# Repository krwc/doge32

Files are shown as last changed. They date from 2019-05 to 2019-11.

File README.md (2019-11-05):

# DOGE32 Features

## Small footprint

The board is 25mm x 59mm, which means it can fit into the standard breadboard nicely, and
each pin will be accessible.

## Battery slot

The board can be powered by 3.7V li-po battery.

## Low power consumption

In deep sleep mode, the board consumes only about 13µA. This is a pretty good result and will
let the device work for a long period of time on a battery.

## Dual supply support

You may power the device from battery as well as from the USB at the same time - useful feature
if you're making some quick fixes to the "already deployed" device.

## Built-in voltage measurement on IO35 pin

The IO35 pin of the ESP32 is connected to the (switchable via IO32), to avoid excessive current
draw input voltage divider, and can be used to determine the battery level of the battery.

## Cutting off the USB-UART converter when powered on from the battery

Many ESP32 boards don't do it, which is a problem, because [not all revisions of CP2102N enter
suspend state correctly](https://www.silabs.com/documents/public/errata/cp2102n-errata.pdf),
which means they draw current (a few milliamps) when they are not supposed to (e.g. when powered
on from the battery). This issue is fixed in our board.

## Slow rising reset fix

[ESP32 has a bug](https://www.esp32.com/viewtopic.php?t=5731) that makes automatic reset during
flashing with tools such as esptool.py not happening, and thus requires manual user intervention.

Our board also incorporates the fix for this problem.

# Renders

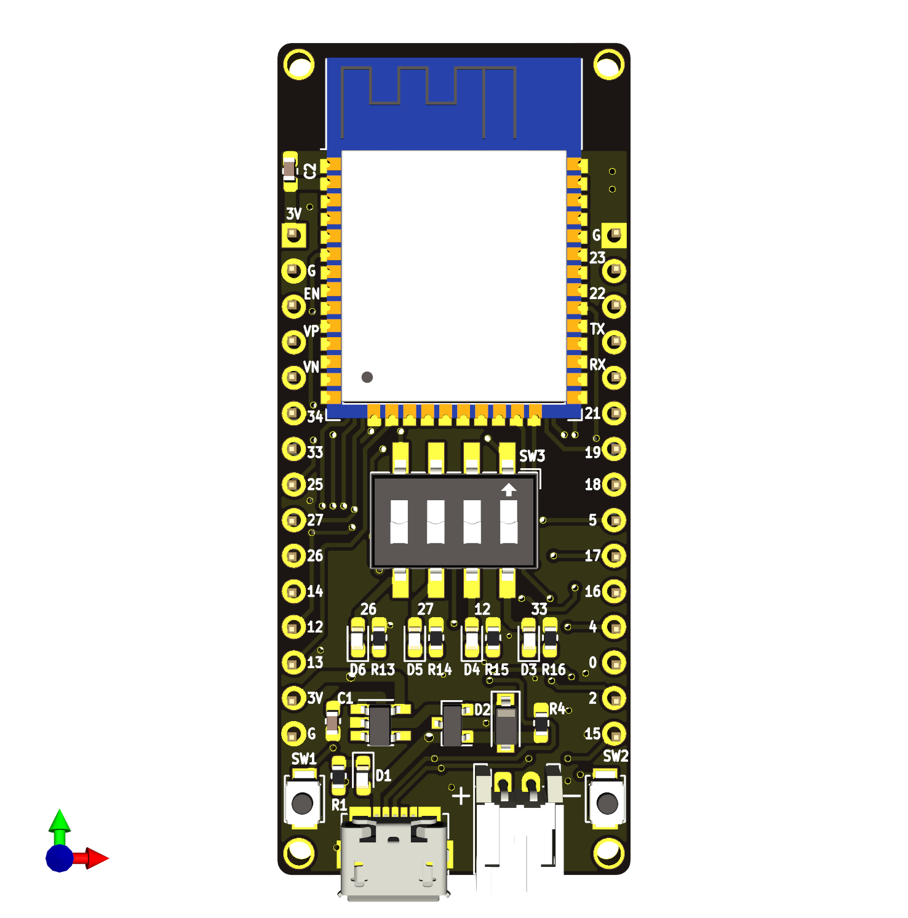
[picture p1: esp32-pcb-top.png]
Top


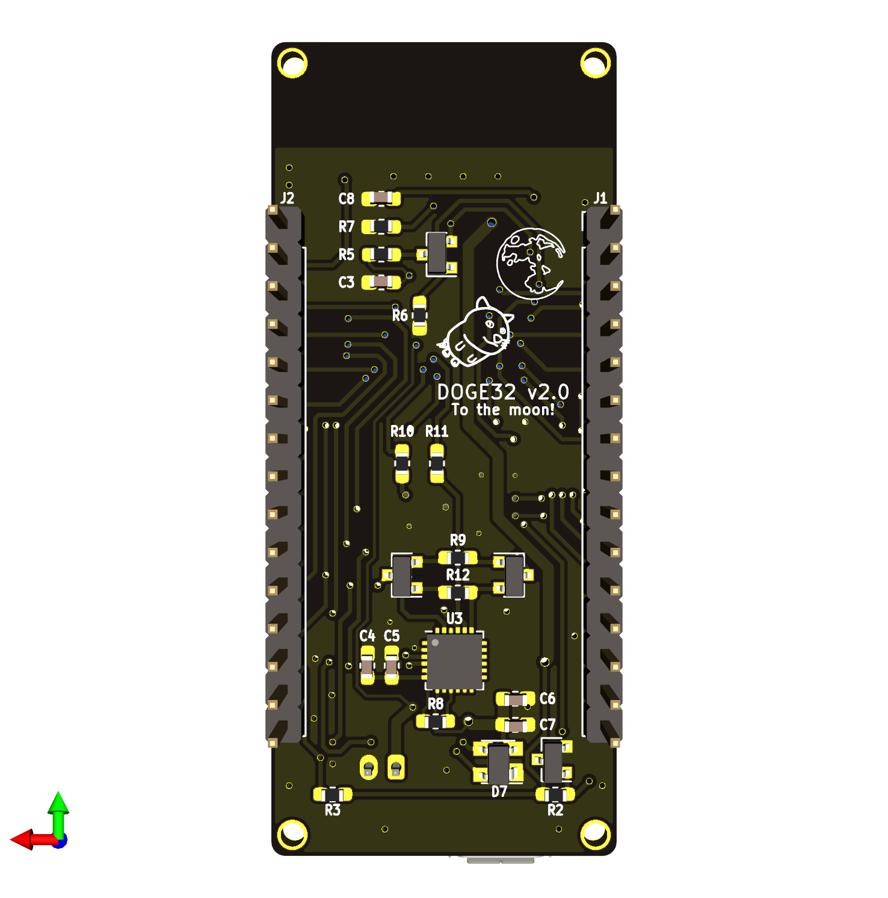
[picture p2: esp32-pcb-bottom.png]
Bottom


# Authors

Me and [dextero](https://github.com/dextero/). The board is an absolute overkill, built to monitor
soil moisture and eventually to help reminiding about watering plants more often ;-).

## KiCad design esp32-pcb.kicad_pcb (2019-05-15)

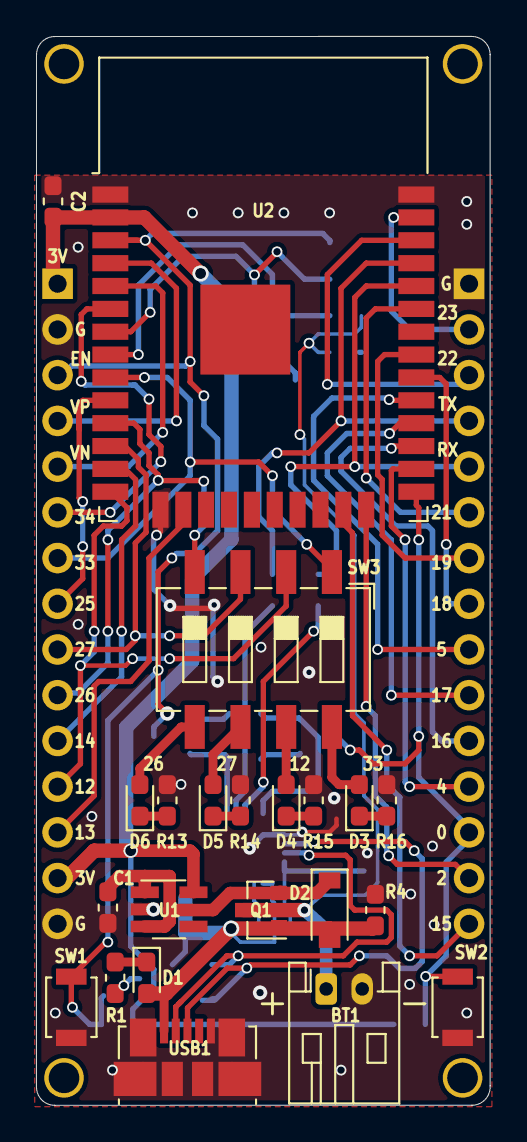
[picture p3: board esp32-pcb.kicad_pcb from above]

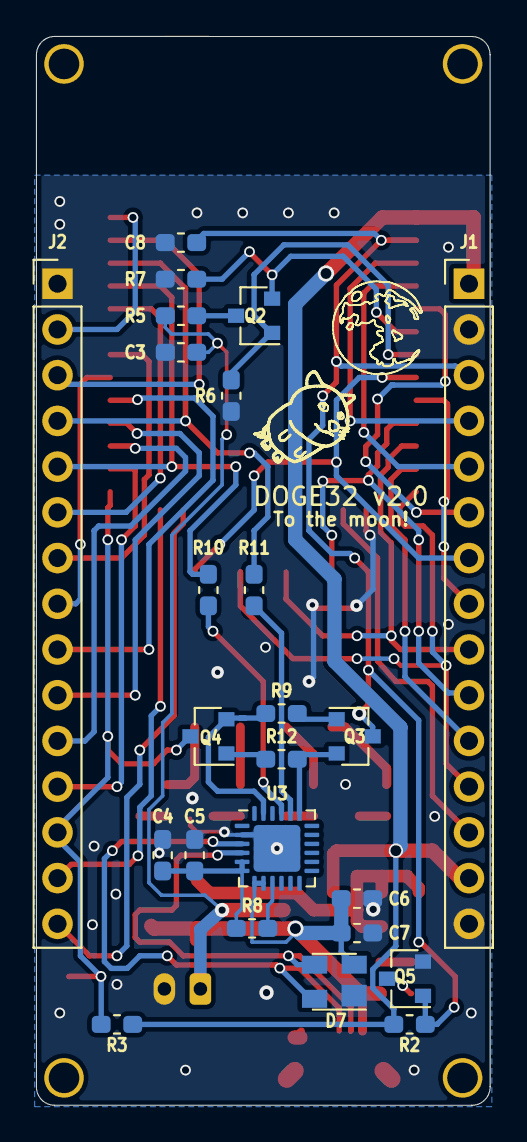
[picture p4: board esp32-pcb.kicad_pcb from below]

Board: 2 copper layers, 25.2 x 59.4 mm, 46 parts (24 on the bottom side), 53 nets.

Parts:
BT1: 3.7V; JST_PH_S2B-PH-K_1x02_P2.00mm_Horizontal
C1, C2: 10uF; C_0603_1608Metric_Pad1.05x0.95mm_HandSolder
C3, C5, C7: 0.1uF; C_0603_1608Metric_Pad1.05x0.95mm_HandSolder
C4, C6, C8: 4.7uF; C_0603_1608Metric_Pad1.05x0.95mm_HandSolder
D1: LED_USB_PWR; LED_0603_1608Metric_Pad1.05x0.95mm_HandSolder
D2: B140HW-7; D_SOD-123
D3: LED_RED; LED_0603_1608Metric_Pad1.05x0.95mm_HandSolder
D4: LED_GREEN; LED_0603_1608Metric_Pad1.05x0.95mm_HandSolder
D5: LED_BLUE; LED_0603_1608Metric_Pad1.05x0.95mm_HandSolder
D6: LED_YELLOW; LED_0603_1608Metric_Pad1.05x0.95mm_HandSolder
D7: SP0503BAHT; SOT-143
J1, J2: Conn_01x15_Male; PinHeader_1x15_P2.54mm_Vertical
Q1: SI2333DDS-T1-GE3; SOT-23
Q2, Q5: BSS138Q-7-F; SOT-23
Q3, Q4: MMBT3904; SOT-23
R1, R8, R10, R11: 1k; R_0603_1608Metric_Pad1.05x0.95mm_HandSolder
R2, R3, R4, R5, R6, R9, R12: 10k; R_0603_1608Metric_Pad1.05x0.95mm_HandSolder
R7: 30k; R_0603_1608Metric_Pad1.05x0.95mm_HandSolder
R13, R14, R15, R16: 470; R_0603_1608Metric_Pad1.05x0.95mm_HandSolder
SW1: RESET; SW_SPST_B3U-1000P
SW2: USER; SW_SPST_B3U-1000P
SW3: SW_DIP_x04; SW_DIP_SPSTx04_Slide_6.7x11.72mm_W8.61mm_P2.54mm_LowProfile
U1: XC6220B331MR; SOT-23-5_HandSoldering
U2: ESP32-WROOM-32
U3: CP2102N-A01-GQFN24; QFN-24-1EP_4x4mm_P0.5mm_EP2.6x2.6mm
USB1: MicroUSB type B; USB_Micro-B_Molex_47346-0001

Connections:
3V3: C2.2, J1.1, J1.14, R2.1, R3.2, U1.5, U2.2
5V_USB: C6.1, C7.1, D1.2, D2.2, D7.2, Q1.1, R4.2, U3.7, U3.8, USB1.1
EN: C8.1, J1.3, Q3.3, Q5.1, R2.2, SW1.2, U2.3
ESP_I34: J1.6, U2.6
ESP_IO0: J2.13, Q4.3, R3.1, SW2.1, U2.25
ESP_IO2: J2.14, U2.24
ESP_IO4: J2.12, U2.26
ESP_IO5: J2.9, U2.29
ESP_IO12: J1.12, SW3.2, U2.14
ESP_IO13: J1.13, U2.16
ESP_IO14: J1.11, U2.13
ESP_IO15: J2.15, U2.23
ESP_IO16: J2.11, U2.27
ESP_IO17: J2.10, U2.28
ESP_IO18: J2.8, U2.30
ESP_IO19: J2.7, U2.31
ESP_IO21: J2.6, U2.33
ESP_IO22: J2.3, U2.36
ESP_IO23: J2.2, U2.37
ESP_IO25: J1.8, U2.10
ESP_IO26: J1.10, SW3.4, U2.11
ESP_IO27: J1.9, SW3.3, U2.12
ESP_IO33: J1.7, SW3.1, U2.9
ESP_RXD0: J2.5, R10.2, U2.34
ESP_SENSOR_VN: J1.5, U2.5
ESP_SENSOR_VP: J1.4, U2.4
ESP_TXD0: J2.4, R11.2, U2.35
GND: BT1.2, C1.2, C2.1, C3.2, C4.2, C5.2, C6.2, C7.2, C8.2, D7.1, J1.2, J1.15, J2.1, Q5.2, R4.1, R6.1, R7.1, R13.2, R14.2, R15.2, R16.2, SW1.1, SW2.2, U1.2, U2.1, U2.15, U2.38, U3.2, U3.25, USB1.5, USB1.6
unnamed: C1.1, D2.1, Q1.2, U1.1, U1.3
unnamed: C4.1, C5.1, R8.2, U3.5, U3.6
unnamed: D1.1, R1.1
unnamed: D3.1, R16.1
unnamed: D3.2, SW3.8
unnamed: D4.1, R15.1
unnamed: D4.2, SW3.7
unnamed: D5.1, R14.1
unnamed: D5.2, SW3.6
unnamed: D6.1, R13.1
unnamed: D6.2, SW3.5
unnamed: Q2.3, R5.1
unnamed: Q3.1, R9.1
unnamed: Q3.2, R12.2, U3.19
unnamed: Q4.1, R12.1
unnamed: Q4.2, R9.2, U3.23
unnamed: Q5.3, R1.2
unnamed: R8.1, U3.9
unnamed: R10.1, U3.21
unnamed: R11.1, U3.20
USB_D+: D7.4, U3.3, USB1.3
USB_D-: D7.3, U3.4, USB1.2
V_BAT: BT1.1, C3.1, Q1.3, R5.2
V_BAT_HALF: Q2.2, R7.2, U2.7
V_BAT_MEASURE: Q2.1, R6.2, U2.8

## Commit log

2019-04-19 Add initial project
    [esp32-pcb.kicad_pcb, esp32-pcb.sch]
2019-04-19 Add battery protection circuit, switching between USB and VBAT.
    [esp32-pcb.sch]
2019-04-20 Changed footprint of all low-power diodes to 0603 (1608m)
    [esp32-pcb.sch]
2019-04-20 Changed LED footprints to 0603 (1608m)
    [esp32-pcb.sch]
2019-04-20 Changed resistors footprint to 0603 (1608m)
    [esp32-pcb.sch]
2019-04-20 Cosmetics: aligned V_IN label, changed R13 type to R_Small
    [esp32-pcb.sch]
2019-04-20 Changed footprint of a dip-switch to something more appropriate
    [esp32-pcb.sch]
2019-04-20 Changed footprints of buttons
    [esp32-pcb.sch]
2019-04-20 Changed capacitors footprints to 0603 (1608m)
    [esp32-pcb.sch]
2019-04-20 Moved input capacitor, so that +5V line is filtered as well. Added small cap on battery output.
    [esp32-pcb.sch]
2019-04-20 Changed filtering caps footprint. 10uF with 0603 footprint is not exactly easy to find.
    [esp32-pcb.sch]
2019-04-20 Changed footprint of S8050 transistors to SOT-23
    [esp32-pcb.sch]
2019-04-20 Use a 2.2k resistor after LED_USB_PWR to ground. Remove 3V3_USB label.
    [esp32-pcb.sch]
2019-04-20 Short J1_PIN2 directly to GND
    [esp32-pcb.sch]
2019-04-20 Short J1_PIN3 to ESP_EN, at the same time, move VP and VN to pins 4 and 5.
    [esp32-pcb.sch]
2019-04-20 Connect IO34 to J1_PIN6
    [esp32-pcb.sch]
2019-04-20 Connect VBAT directly to IO35
    [esp32-pcb.sch]
2019-04-20 Implement on-demand battery measurement circuit, providing half of battery voltage to measure.
    [esp32-pcb.sch]
2019-04-20 Replace BJTs with FETs
    [esp32-pcb.sch]
2019-04-20 Actually fix the circuit responsible for "auto programming"
    [esp32-pcb.sch]
2019-04-21 Revert using FETs for DTR and RTS switching. They are not as cheap as NPNs. Also, add a gate pulldown in battery measurement switch.
    [esp32-pcb.sch]
2019-04-21 Change footprint of 10uF capacitors once again to 0603.
    [esp32-pcb.sch]
2019-04-21 Modified CP2102N schematics to align with the old one
2019-04-21 Reworked USB-UART diagram: - added bypass capacitors for VBUS/REGIN and VIO/VDD as the datasheet suggests, - power is now delivered only from the USB port, - used regulated 3.3V VDD to bias VIO, - re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
    [esp32-pcb.sch]
2019-04-21 Make dipswitch 4-pin
    [esp32-pcb.sch]
2019-04-21 Reconnected every ESP32 pin following the order as in Figure 1 in ESP32-WROOM-32 datasheet
    [esp32-pcb.sch]
2019-04-26 Created PCB layout. Used JST-PH 2mm connector.
    [esp32-pcb.kicad_pcb, esp32-pcb.sch]
2019-04-26 Label every goldpin, and align other labels so that they are readable
    [esp32-pcb.kicad_pcb]
2019-04-26 Made sure all components and their labels are by default visible
    [esp32-pcb.kicad_pcb]
2019-04-26 Changed zones clearance to 0.25mm
    [esp32-pcb.kicad_pcb]
2019-04-26 Added mounting holes
    [esp32-pcb.kicad_pcb]
2019-04-26 Cleaned up tracks and vias
    [esp32-pcb.kicad_pcb]
2019-04-26 Do not place via on a pad if it is not necessary
    [esp32-pcb.kicad_pcb]
2019-04-26 Added proper mounting holes
    [esp32-pcb.kicad_pcb]
2019-04-26 Much pcb, very esp
    [esp32-pcb.kicad_pcb]
2019-04-26 Move doge to B.SilkS layer
    [esp32-pcb.kicad_pcb]
2019-04-26 Make layers visible again
    [esp32-pcb.kicad_pcb]
2019-04-26 Make battery power line 0.7mm
    [esp32-pcb.kicad_pcb]
2019-04-26 Added even more vias and aligned them so that they do not interfere with graphics
    [esp32-pcb.kicad_pcb]
2019-04-26 Adapted replacement of DOGE to DOGE32
    [esp32-pcb.kicad_pcb]
2019-04-26 Remove weird connection that did nothing
    [esp32-pcb.sch]
2019-04-26 Added TVS protection
    [esp32-pcb.kicad_pcb, esp32-pcb.sch]
2019-04-26 Updated to match final list of bought components
    [esp32-pcb.sch]
2019-04-29 Increase 5V input trace width to 0.5mm
    [esp32-pcb.kicad_pcb]
2019-05-05 Update resistor values with actually used ones. Move CP2102N and SI2333 to esp32-pcb.lib
    [esp32-pcb.kicad_pcb, esp32-pcb.sch]
2019-05-05 Update PCB
    [esp32-pcb.kicad_pcb]
2019-05-05 Add 4.7uF capacitor between EN and GND to ensure EN rising edge is slow
    [esp32-pcb.kicad_pcb, esp32-pcb.sch]
2019-05-05 Fix battery protection circuit by swapping terminals of p-MOS
    [esp32-pcb.kicad_pcb, esp32-pcb.sch]
2019-05-06 Use B140HW-7 Schottky diode instead of SD0805S020S1R0. The new diode has much lower guaranteed reverse current of 40µA rather than 0.2mA
    [esp32-pcb.kicad_pcb, esp32-pcb.sch]
2019-05-06 Use larger resistors for blue LEDs
    [esp32-pcb.kicad_pcb, esp32-pcb.sch]
2019-05-06 Turn off USB PWR led when the board is under reset
    [esp32-pcb.kicad_pcb, esp32-pcb.sch]
2019-05-06 Fix D2 text. Eliminate overlaps
    [esp32-pcb.kicad_pcb]
2019-05-06 Connect D4 to IO12
    [esp32-pcb.kicad_pcb, esp32-pcb.sch]
2019-05-06 Label diodes with IO ports they are connected to
    [esp32-pcb.kicad_pcb]
2019-05-06 Remove garbage D6 text hidden somewhere outside of the sheet
    [esp32-pcb.kicad_pcb]
2019-05-13 Add clear battery polarization indicators to the silkscreen. Bump revision to v2.0
    [esp32-pcb.kicad_pcb]
2019-05-15 Use 1k resistor instead of 2k for green PWR led
    [esp32-pcb.kicad_pcb, esp32-pcb.sch]
2019-05-15 Use XC6220B331MR
    [esp32-pcb.kicad_pcb, esp32-pcb.sch]
2019-05-15 Use 30k resistor for R7 so that 0.75 * VBAT is dropped at it instead of 0.5*VBAT. This should improve battery reading precision
    [esp32-pcb.kicad_pcb, esp32-pcb.sch]
2019-05-15 Move C1 a bit, so that the left corner GND and 3V labels are more visible
    [esp32-pcb.kicad_pcb]
2019-10-26 Mention small PCB footprint
